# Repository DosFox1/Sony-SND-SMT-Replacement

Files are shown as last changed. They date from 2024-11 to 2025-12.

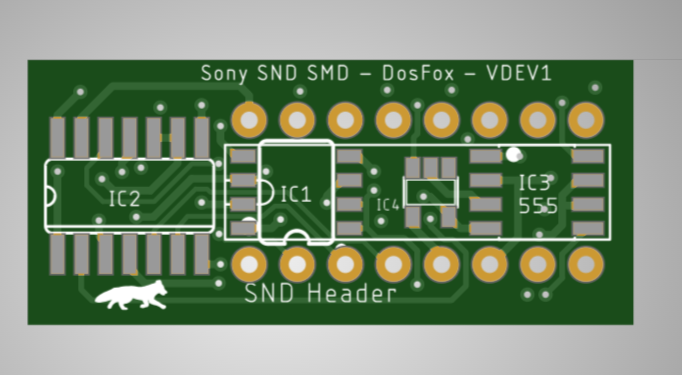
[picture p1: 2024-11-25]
Images/Sony SND SMD Front.png

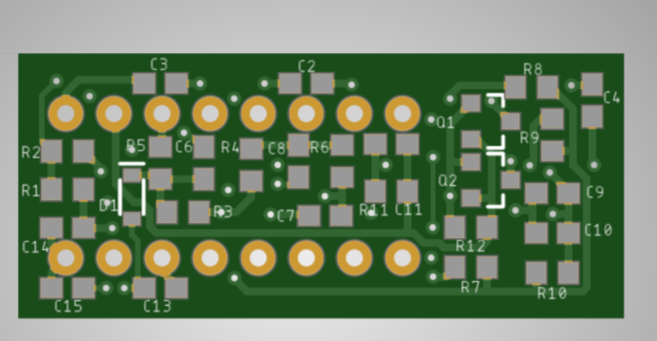
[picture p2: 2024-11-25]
Images/Sony SND SMD Back.png

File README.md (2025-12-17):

# Sony-SND-SMT-Replacement
BETA -
A replacement for the Sony SND IC (part number 343-0045-A) as used on the Macintosh Plus, SE and others, using SMD parts.




# So what is it?
This is a variant of my existing Sony SND replacement, however, it uses purely SMD parts. 
My original repo for the through hole variant can be found here:
https://github.com/DosFox1/Sony-SND-THT-Replacement

The design is effectively the same - tincluding the annoying requirement to tap -12v from the board. If it aint broke, don't fix it!
Turns out removing -12v makes the audio output unhappy. So make sure you leave that in. 
POR works though - just make sure the pullup resistor from the POR switch is removed (I.E, R21 on the Mac Plus board). 

**NOTE - This is Completely Untested**
# Bill Of Materials:
```blocks
Part     Value          Device                       Package  Library                Sheet

C1       100n 16V       100N_CAP_0603                C0603    Capacitors SMD         1
C2       100n 16V       100N_CAP_0603                C0603    Capacitors SMD         1
C3       100n 16V       100N_CAP_0603                C0603    Capacitors SMD         1
C4       100n 16V       100N_CAP_0603                C0603    Capacitors SMD         1
C5       1u 16V         1U_CAP_0603                  C0603    Capacitors SMD         1
C6       100n 16V       100N_CAP_0603                C0603    Capacitors SMD         1
C7       470p           470P_CAP_0603                C0603    Capacitors SMD         1
C8       1n 50V         1N_CAP_0603                  C0603    Capacitors SMD         1
C9       100n 16V       100N_CAP_0603                C0603    Capacitors SMD         1
C10      100n 16V       100N_CAP_0603                C0603    Capacitors SMD         1
C11      220p           220P_CAP_0603                C0603    Capacitors SMD         1
C12      100n 16V       100N_CAP_0603                C0603    Capacitors SMD         1
D1       5.1V           DIODE-ZENER-MMSZ5231B        SOD-123  SparkFun-DiscreteSemi  1
IC1      TL072          OPAMP-DUALU                  SO08     SparkFun-IC-Amplifiers 1
IC2      4016D          4016D                        SO14     40xx                   1
IC3      NE555DRG4      555_SOIC8                    SOIC8    ICs                    1
IC4      74LVC1G06DBV   74LVC1G06DBV                 SOT23-5  74xx-little-us         1
IC5      Turned pins    SND THT turned pins          DIP16    Pins                   1
Q1       MMBT3906       TRANS_PNP-PMBT3906|MMBT3906L SOT23-3  SparkFun-DiscreteSemi  1
Q2       MMBT3904       TRANS_NPN-MMBT2222AL         SOT23-3  SparkFun-DiscreteSemi  1
R1       1M             GENERIC_RESISTOR_0603        R0603    Resistors SMD          1
R2       1M             GENERIC_RESISTOR_0603        R0603    Resistors SMD          1
R3       6K8            GENERIC_RESISTOR_0603        R0603    Resistors SMD          1
R4       47K            47K_RESISTOR                 R0603    Resistors SMD          1
R5       1k             1K_RESISTOR_0603             R0603    Resistors SMD          1
R6       47K            47K_RESISTOR                 R0603    Resistors SMD          1
R7       68K            GENERIC_RESISTOR_0603        R0603    Resistors SMD          1
R8       150K           GENERIC_RESISTOR_0603        R0603    Resistors SMD          1
R9       470K           GENERIC_RESISTOR_0603        R0603    Resistors SMD          1
R10      470K           GENERIC_RESISTOR_0603        R0603    Resistors SMD          1
R11      200K           GENERIC_RESISTOR_0603        R0603    Resistors SMD          1
R12      150R           150R_RESISTOR_0603           R0603    Resistors SMD          1
```

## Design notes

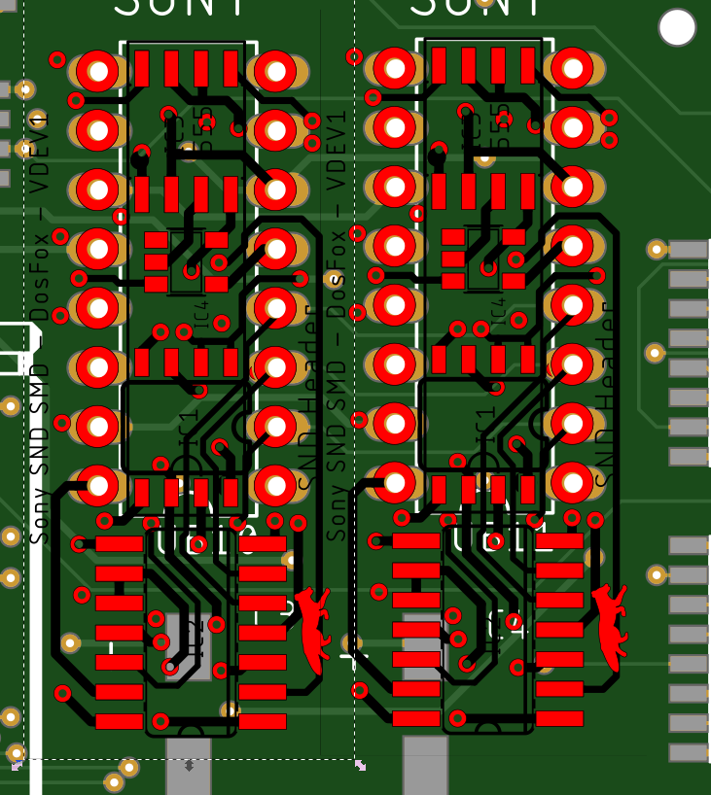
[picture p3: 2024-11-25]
Images/SE30 vs SMD SND.png

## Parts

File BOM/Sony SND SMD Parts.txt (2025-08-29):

Partlist

Exported from SND_SMD_Replacement.sch at 25/Oct/24 14:49

EAGLE Version 9.6.2 Copyright (c) 1988-2020 Autodesk, Inc.

Assembly variant: 

Part     Value          Device                       Package  Library                Sheet

C1       100n 16V       100N_CAP_0603                C0603    Capacitors SMD         1
C2       100n 16V       100N_CAP_0603                C0603    Capacitors SMD         1
C3       100n 16V       100N_CAP_0603                C0603    Capacitors SMD         1
C4       100n 16V       100N_CAP_0603                C0603    Capacitors SMD         1
C5       1u 16V         1U_CAP_0603                  C0603    Capacitors SMD         1
C6       100n 16V       100N_CAP_0603                C0603    Capacitors SMD         1
C7       470p           470P_CAP_0603                C0603    Capacitors SMD         1
C8       1n 50V         1N_CAP_0603                  C0603    Capacitors SMD         1
C9       100n 16V       100N_CAP_0603                C0603    Capacitors SMD         1
C10      100n 16V       100N_CAP_0603                C0603    Capacitors SMD         1
C11      220p           220P_CAP_0603                C0603    Capacitors SMD         1
C13      100n 16V       100N_CAP_0603                C0603    Capacitors SMD         1
D1       5.1V           DIODE-ZENER-MMSZ5231B        SOD-323  SparkFun-DiscreteSemi  1
IC1      TL072          OPAMP-DUALU                  SO08     SparkFun-IC-Amplifiers 1
IC2      4016D          4016D                        SO14     40xx                   1
IC3      NE555DRG4      555_SOIC8                    SOIC8    ICs                    1
IC4      74LVC1G06DBV   74LVC1G06DBV                 SOT23-5  74xx-little-us         1
IC5                     SND                          DIP16    ICs                    1
Q1       MMBT3906       TRANS_PNP-PMBT3906|MMBT3906L SOT23-3  SparkFun-DiscreteSemi  1
Q2       MMBT3904       TRANS_NPN-MMBT2222AL         SOT23-3  SparkFun-DiscreteSemi  1
R1       1M             GENERIC_RESISTOR_0603        R0603    Resistors SMD          1
R2       1M             GENERIC_RESISTOR_0603        R0603    Resistors SMD          1
R3       6K8            GENERIC_RESISTOR_0603        R0603    Resistors SMD          1
R4       47K            47K_RESISTOR                 R0603    Resistors SMD          1
R5       1k             1K_RESISTOR_0603             R0603    Resistors SMD          1
R6       47K            47K_RESISTOR                 R0603    Resistors SMD          1
R7       68K            GENERIC_RESISTOR_0603        R0603    Resistors SMD          1
R8       150K           GENERIC_RESISTOR_0603        R0603    Resistors SMD          1
R9       470K           GENERIC_RESISTOR_0603        R0603    Resistors SMD          1
R10      470K           GENERIC_RESISTOR_0603        R0603    Resistors SMD          1
R11      200K           GENERIC_RESISTOR_0603        R0603    Resistors SMD          1
R12      150R           150R_RESISTOR_0603           R0603    Resistors SMD          1

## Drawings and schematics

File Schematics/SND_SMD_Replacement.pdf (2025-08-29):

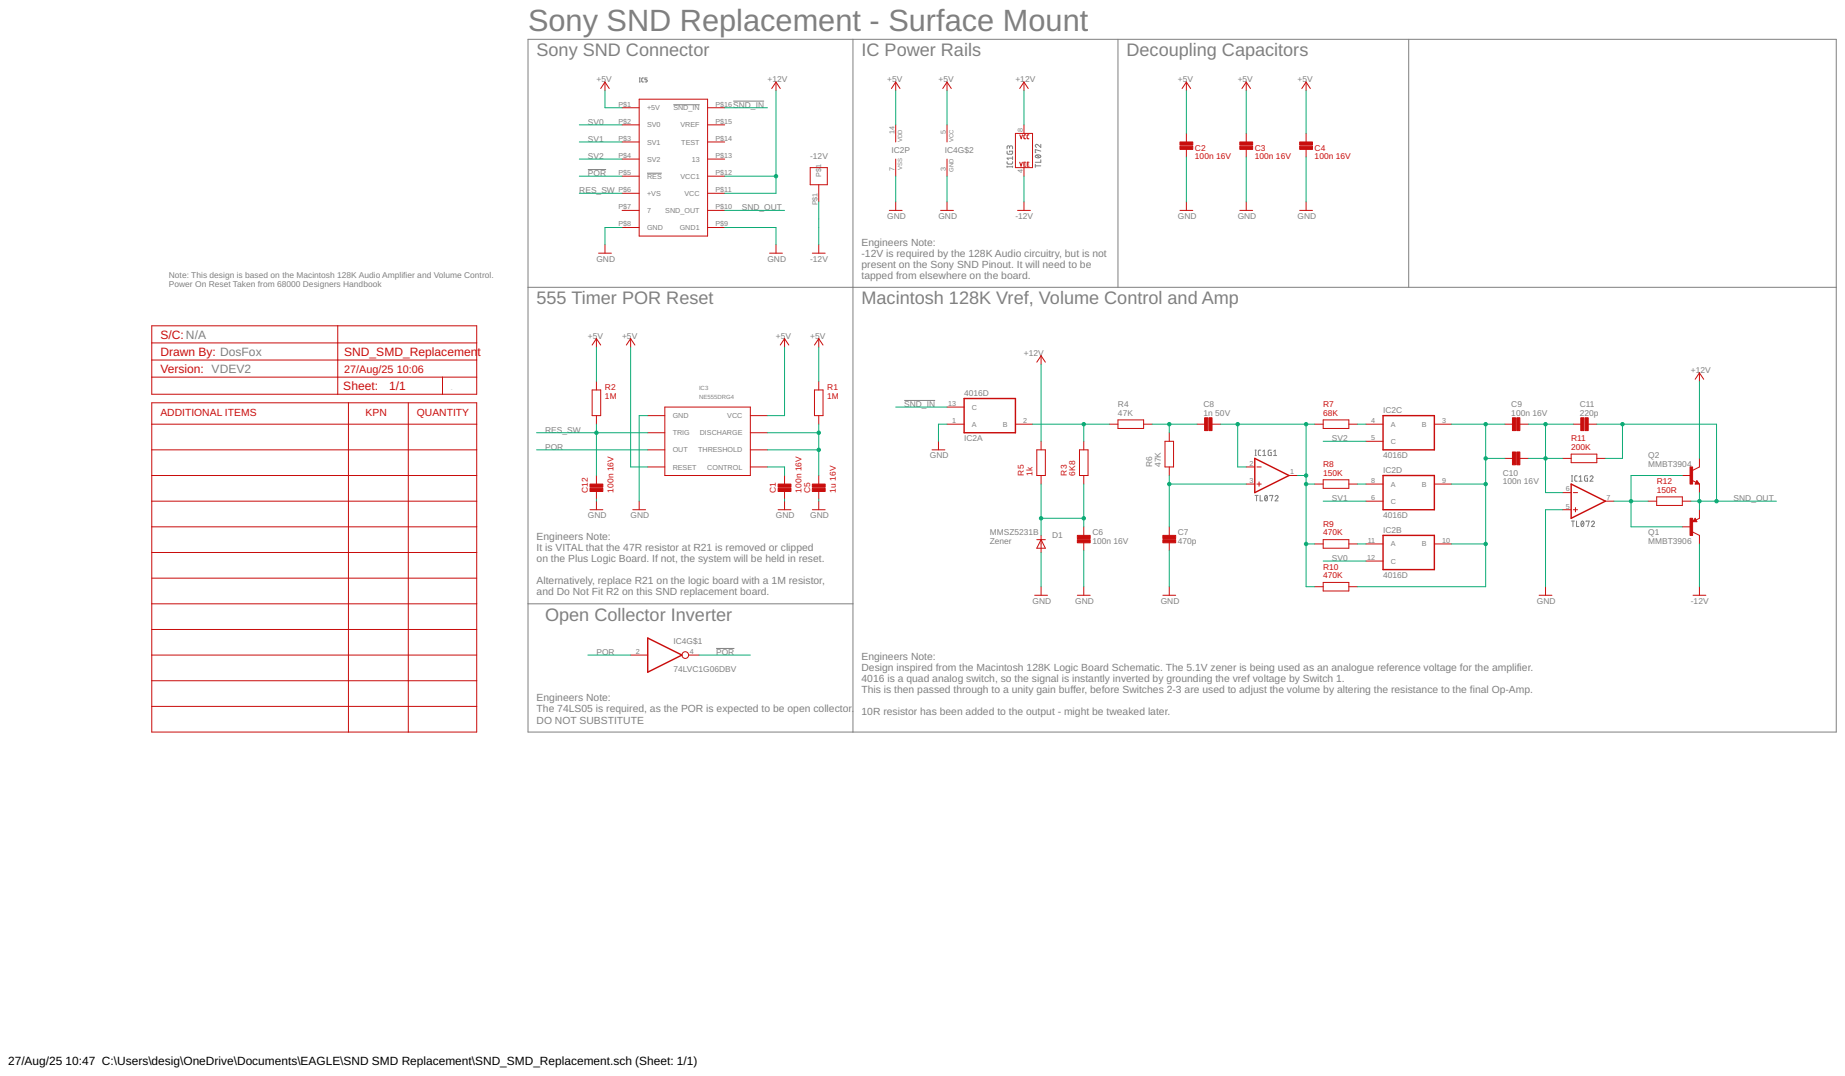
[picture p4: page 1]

Sony SND Replacement - Surface Mount

Engineers Note: -12V is required by the 128K Audio circuitry, but is not

present on the Sony SND Pinout. It will need to be

Note: This design is based on the Macintosh 128K Audio Amplifier and Volume Control. Power On Reset Taken from 68000 Designers Handbook

555 Timer POR Reset +5V Engineers Note: | +5V | +5V | +5V | tapped from elsewhere on the board. VDEV2 Macintosh 128K Vref, Volume Control and Amp +12V

S/C: N/A
Drawn By: DosFox | SND_SMD_Replacement
Version: | 27/Aug/25 10:06

Sheet: 1/1

It is VITAL that the 47R resistor at R21 is removed or clipped
on the Plus Logic Board. If not, the system will be held in reset. Alternatively, replace R21 on the logic board with a 1M resistor, and Do Not Fit R2 on this SND replacement board.

Engineers Note:
Design inspired from the Macintosh 128K Logic Board Schematic. The 5.1V zener is being used as an analogue reference voltage for the amplifier. 4016 is a quad analog switch, so the signal is instantly inverted by grounding the vref voltage by Switch 1. This is then passed through to a unity gain buffer, before Switches 2-3 are used to adjust the volume by altering the resistance to the final Op-Amp. 10R resistor has been added to the output - might be tweaked later.

The 74LS05 is required, as the POR is expected to be open collector. DO NOT SUBSTITUTE

27/Aug/25 10:47 C:\Users\desig\OneDrive\Documents\EAGLE\SND SMD Replacement\SND_SMD_Replacement.sch (Sheet: 1/1)

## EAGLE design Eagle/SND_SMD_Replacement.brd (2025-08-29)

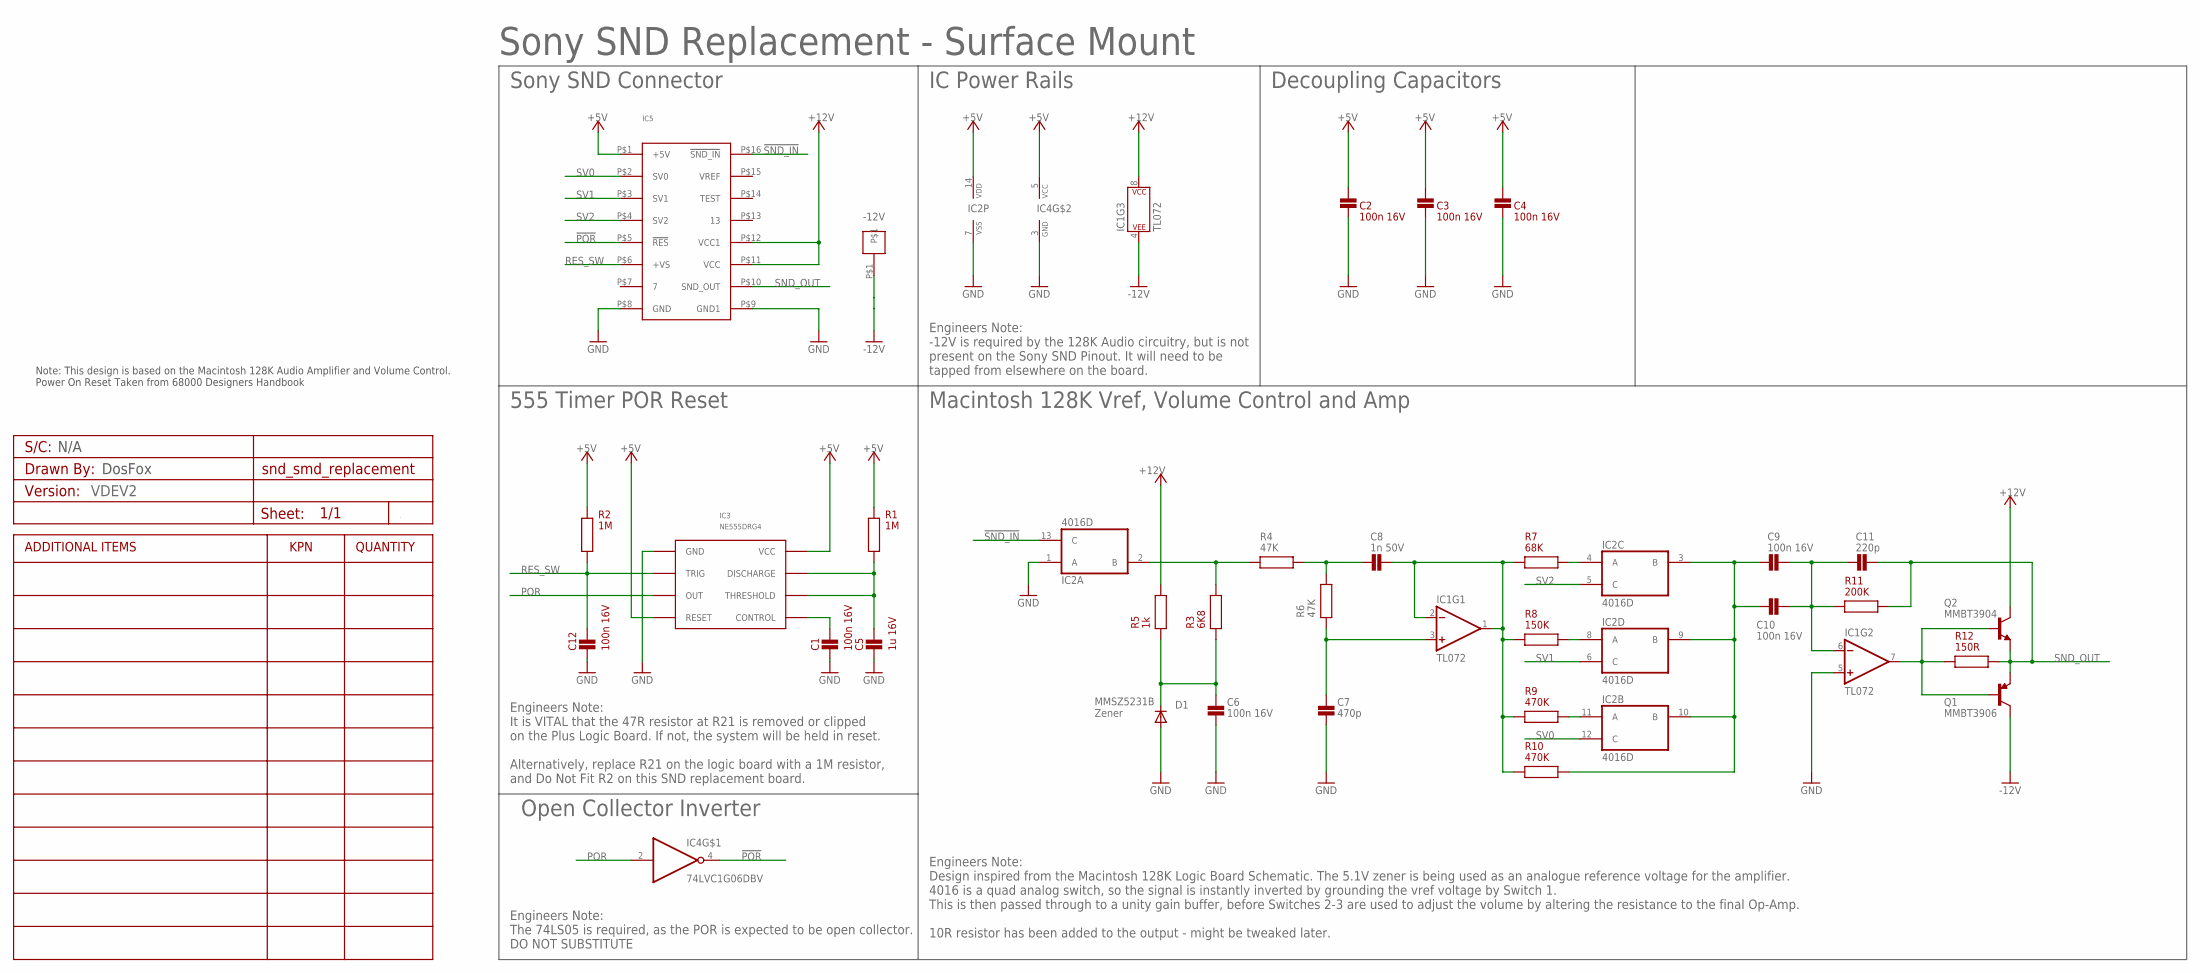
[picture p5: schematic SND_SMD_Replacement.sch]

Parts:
-12V: PADS_1W_SMD; SINGLE_CONN_SMD
A1: VDEV2; PCB_CUSTOM_DETAILS
C1, C2, C3, C4, C6, C9, C10, C12: 100n 16V; C0603
C5: 1u 16V; C0603
C7: 470p; C0603
C8: 1n 50V; C0603
C11: 220p; C0603
D1: 5.1V; SOD-123
IC1: TL072; SO08
IC2: 4016D; SO14
IC3: NE555DRG4; SOIC8
IC4: 74LVC1G06DBV; SOT23-5
IC5: SND; DIP16
Q1: MMBT3906; SOT23-3
Q2: MMBT3904; SOT23-3
R1, R2: 1M; R0603
R3: 6K8; R0603
R4, R6: 47K; R0603
R5: 1k; R0603
R7: 68K; R0603
R8: 150K; R0603
R9, R10: 470K; R0603
R11: 200K; R0603
R12: 150R; R0603

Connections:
!POR: IC4.4 (O), IC5.P$5 (!RES)
!SND_IN: IC2.13 (C), IC5.P$16 (!SND_IN)
+5V: C2.2, C3.2, C4.2, IC2.14 (VDD), IC3.P$4 (RESET), IC3.P$8 (VCC), IC4.5 (VCC), IC5.P$1 (+5V), R1.2, R2.2
+12V: IC1.8 (P$V+), IC5.P$11 (VCC), IC5.P$12 (VCC1), Q2.3 (C), R5.2
-12V: -12V.P$1, IC1.4 (P$V-), Q1.3 (C)
GND: C1.1, C2.1, C3.1, C4.1, C5.1, C6.1, C7.1, C12.1, D1.A, IC1.5 (+IN), IC2.1 (A), IC2.7 (VSS), IC3.P$1 (GND), IC4.3 (GND), IC5.P$8 (GND), IC5.P$9 (GND1)
unnamed: IC2.2 (B), R3.2, R4.1
unnamed: C9.1, C10.1, IC2.3 (B), IC2.9 (B), IC2.10 (B), R10.2
unnamed: C8.1, R4.2, R6.2
unnamed: C6.2, D1.C, R3.1, R5.1
unnamed: C7.2, IC1.3 (+IN), R6.1
unnamed: IC2.4 (A), R7.2
unnamed: IC2.8 (A), R8.2
unnamed: IC2.11 (A), R9.2
unnamed: C9.2, C10.2, C11.1, IC1.6 (-IN), R11.1
unnamed: C5.2, IC3.P$6 (THRESHOLD), IC3.P$7 (DISCHARGE), R1.1
unnamed: C8.2, IC1.1 (OUT), IC1.2 (-IN), R7.1, R8.1, R9.1, R10.1
unnamed: IC1.7 (OUT), Q1.1 (B), Q2.1 (B), R12.1
unnamed: C1.2, IC3.P$5 (CONTROL)
POR: IC3.P$3 (OUT), IC4.2 (I)
RES_SW: C12.2, IC3.P$2 (TRIG), IC5.P$6 (+VS), R2.1
SND_OUT: C11.2, IC5.P$10 (SND_OUT), Q1.2 (E), Q2.2 (E), R11.2, R12.2
SV0: IC2.12 (C), IC5.P$2 (SV0)
SV1: IC2.6 (C), IC5.P$3 (SV1)
SV2: IC2.5 (C), IC5.P$4 (SV2)

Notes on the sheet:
Note: This design is based on the Macintosh 128K Audio Amplifier and Volume Control. Power On Reset Taken from 68000 Designers Handbook
DosFox
N/A
MMSZ5231B Zener
Sony SND Replacement - Surface Mount
Sony SND Connector
IC Power Rails
Decoupling Capacitors
555 Timer POR Reset
Open Collector Inverter
Macintosh 128K Vref, Volume Control and Amp
Engineers Note: Design inspired from the Macintosh 128K Logic Board Schematic. The 5.1V zener is being used as an analogue reference voltage for the amplifier. 4016 is a quad analog switch, so the signal is instantly inverted by grounding the vref voltage by Switch 1. This is then passed through to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
Engineers Note: It is VITAL that the 47R resistor at R21 is removed or clipped on the Plus Logic Board. If not, the system will be held in reset. Alternatively, replace R21 on the logic board with a 1M resistor, and Do Not Fit R2 on this SND replacement board.
Engineers Note: The 74LS05 is required, as the POR is expected to be open collector. DO NOT SUBSTITUTE
Engineers Note: -12V is required by the 128K Audio circuitry, but is not present on the Sony SND Pinout. It will need to be tapped from elsewhere on the board.

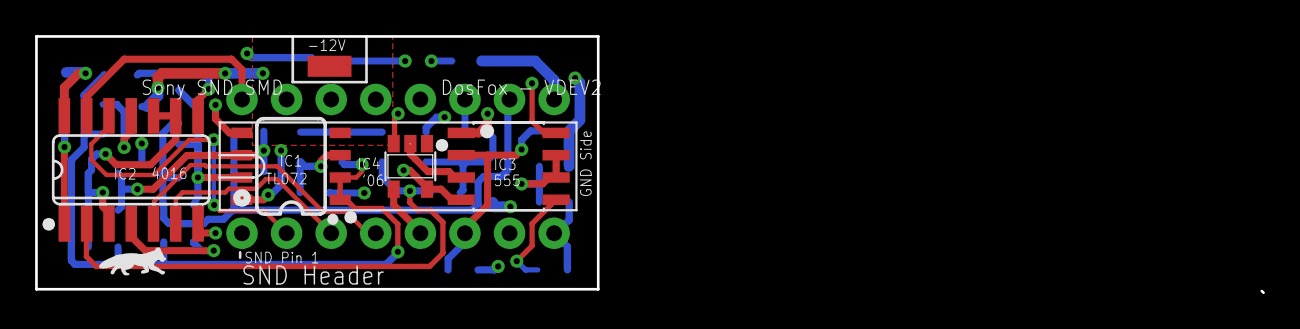
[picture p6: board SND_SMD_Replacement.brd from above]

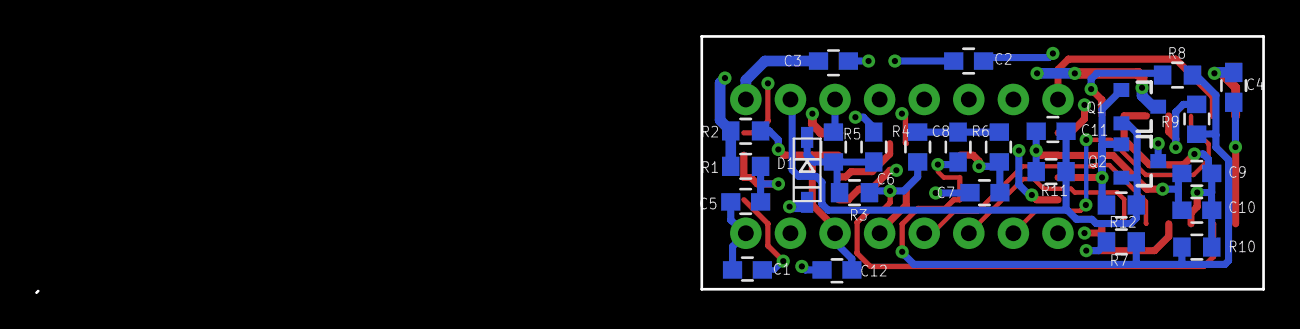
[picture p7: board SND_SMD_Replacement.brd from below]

Board: 4 copper layers, 32.0 x 14.4 mm, 34 parts (27 on the bottom side), 25 nets.

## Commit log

2024-11-25 Add files via upload
    Initial commit of files and associated directories - VDEV1 not tested still.
    [SND_SMD_Replacement.brd, SND_SMD_Replacement.sch]
2024-11-29 Add files via upload
    oops. Fixed output of gerbers being four layers instead of two.
2024-12-02 Add files via upload
    Exported gerbers via KiCAD, EAGLE doesn't like four layer boards.
    Fingers crossed this works (sorry!)
2025-08-29 Updated README with VDEV2
    VDEV2 BOM and new photos added

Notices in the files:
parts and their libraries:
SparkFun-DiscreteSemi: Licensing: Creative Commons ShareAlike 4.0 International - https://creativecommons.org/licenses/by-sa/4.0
